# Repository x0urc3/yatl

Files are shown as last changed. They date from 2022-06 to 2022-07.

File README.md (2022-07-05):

# [Work-in-Progress] Yet Another Temperature Logger
A coin cell powered precision temperature logger

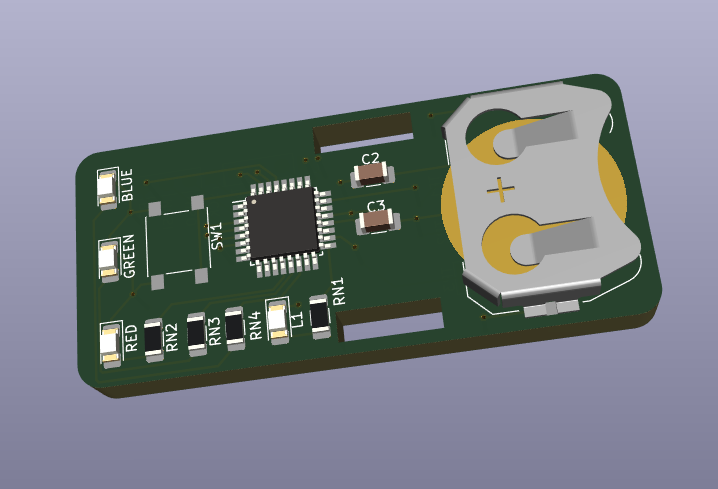
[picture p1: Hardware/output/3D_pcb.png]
PCB 3D view


# Development tools
1. [Kicad](https://www.kicad.org/)
2. [PlatformIO](https://platformio.org/)
3. Python/Bash

# Release
## Version 0.5
- Initial prototype
- ATMega48 microcontroller and LMT86 temperature sensor
- Temperature data is stored in the ATMega48 EEPROM. Sampled every 2 minutes for a duration of 8 hours

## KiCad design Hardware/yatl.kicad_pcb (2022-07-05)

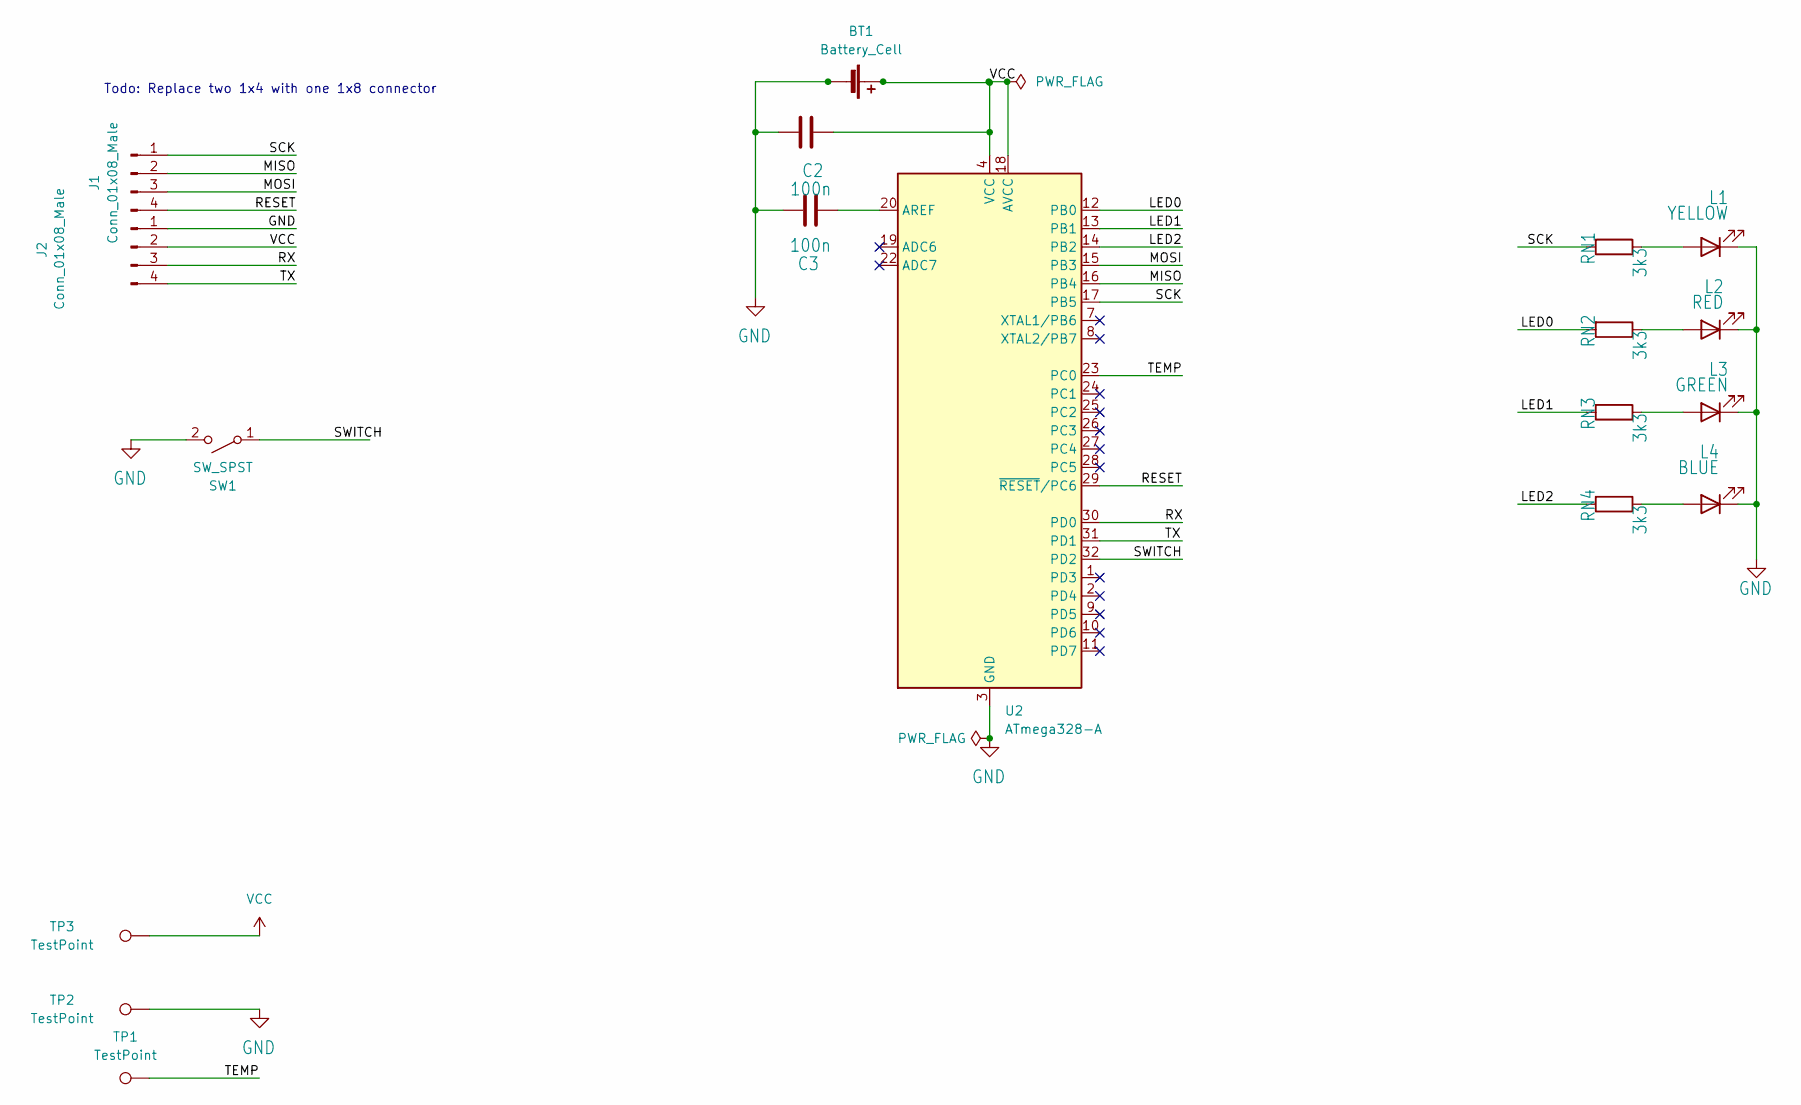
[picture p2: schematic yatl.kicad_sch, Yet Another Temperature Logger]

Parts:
BT1: Battery_Cell; BatteryHolder_Keystone_3034_1x20mm
C2, C3: 100n; C_1206_3216Metric_Pad1.33x1.80mm_HandSolder
J1, J2: Conn_01x08_Male; Testpoint_1x04_P2.54mm
L1: YELLOW; LED_1206_3216Metric_Pad1.42x1.75mm_HandSolder
L2: RED; LED_1206_3216Metric_Pad1.42x1.75mm_HandSolder
L3: GREEN; LED_1206_3216Metric_Pad1.42x1.75mm_HandSolder
L4: BLUE; LED_1206_3216Metric_Pad1.42x1.75mm_HandSolder
RN1, RN2, RN3, RN4: 3k3; R_1206_3216Metric_Pad1.30x1.75mm_HandSolder
SW1: SW_SPST; SW_Push_1P1T_NO_6x6mm_H9.5mm
TP1, TP2, TP3: TestPoint; TestPoint_Pad_3.0x3.0mm
U2: ATmega328-A; TQFP-32_7x7mm_P0.8mm

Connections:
/LED0: RN2.2, U2.12 (PB0)
/LED1: RN3.2, U2.13 (PB1)
/LED2: RN4.2, U2.14 (PB2)
/MISO: J1.2, U2.16 (PB4)
/MOSI: J1.3, U2.15 (PB3)
/RESET: J1.4, U2.29 (~RESET/PC6)
/RX: J2.3, U2.30 (PD0)
/SCK: J1.1, RN1.2, U2.17 (PB5)
/SWITCH: SW1.1 (A), U2.32 (PD2)
/TEMP: TP1.1, U2.23 (PC0)
/TX: J2.4, U2.31 (PD1)
GND: BT1.2 (-), C2.1, C3.2, J2.1, L1.1 (K), L2.1 (K), L3.1 (K), L4.1 (K), SW1.2 (B), TP2.1, U2.3 (GND), U2.5 (GND), U2.21 (GND)
unnamed: C3.1, U2.20 (AREF)
unnamed: L1.2 (A), RN1.1
unnamed: L2.2 (A), RN2.1
unnamed: L3.2 (A), RN3.1
unnamed: L4.2 (A), RN4.1
VCC: BT1.1 (+), C2.2, J2.2, TP3.1, U2.4 (VCC), U2.6 (VCC), U2.18 (AVCC)

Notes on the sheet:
Todo: Replace two 1x4 with one 1x8 connector

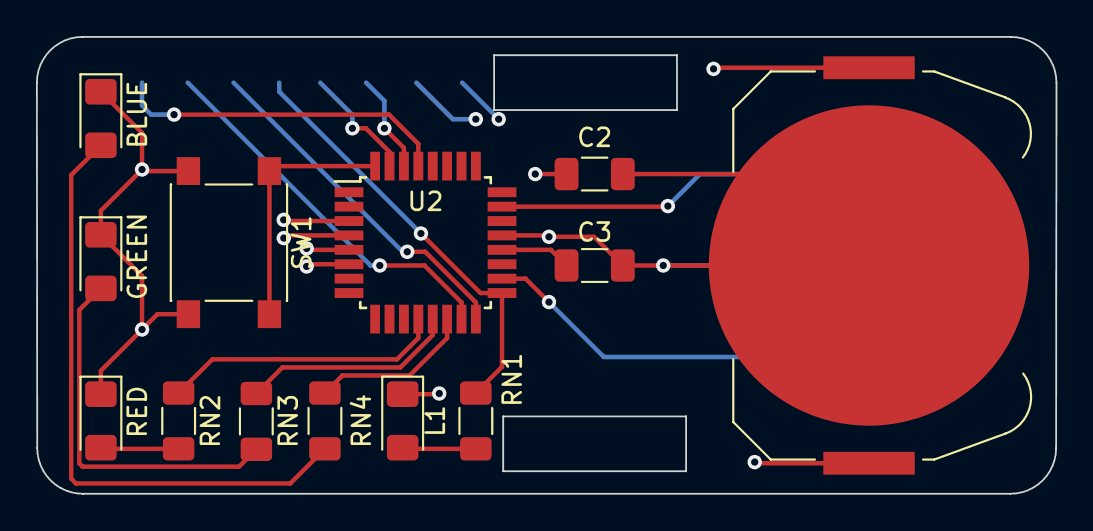
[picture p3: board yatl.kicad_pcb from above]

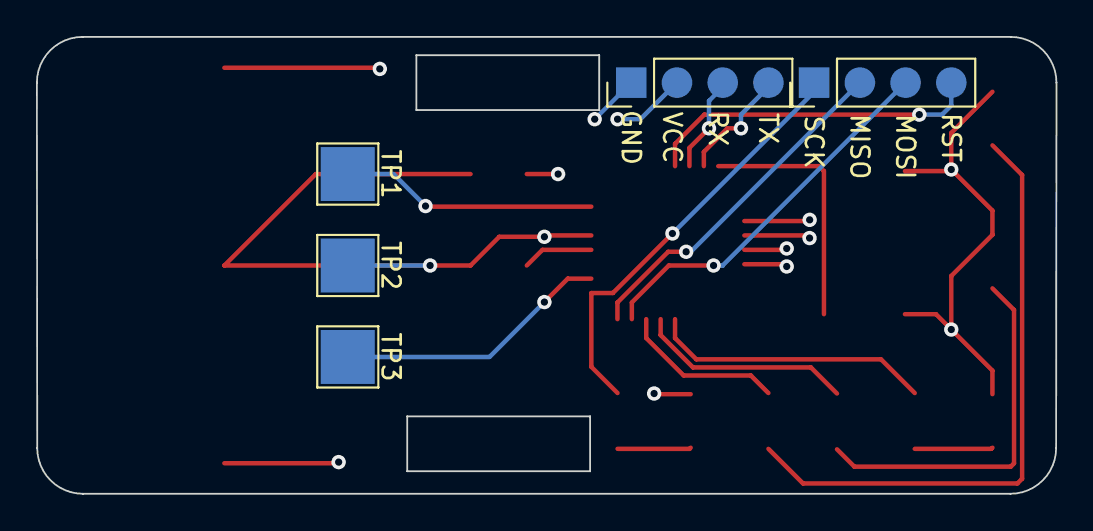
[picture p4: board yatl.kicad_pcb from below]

Board: 4 copper layers, 56.6 x 25.4 mm, 18 parts (5 on the bottom side), 18 nets.

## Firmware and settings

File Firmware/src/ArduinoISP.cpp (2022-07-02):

// ArduinoISP
// Copyright (c) 2008-2011 Randall Bohn
// If you require a license, see
// https://opensource.org/licenses/bsd-license.php
//
// This sketch turns the Arduino into a AVRISP using the following Arduino pins:
//
// Pin 10 is used to reset the target microcontroller.
//
// By default, the hardware SPI pins MISO, MOSI and SCK are used to communicate
// with the target. On all Arduinos, these pins can be found
// on the ICSP/SPI header:
//
//               MISO °. . 5V (!) Avoid this pin on Due, Zero...
//               SCK   . . MOSI
//                     . . GND
//
// On some Arduinos (Uno,...), pins MOSI, MISO and SCK are the same pins as
// digital pin 11, 12 and 13, respectively. That is why many tutorials instruct
// you to hook up the target to these pins. If you find this wiring more
// practical, have a define USE_OLD_STYLE_WIRING. This will work even when not
// using an Uno. (On an Uno this is not needed).
//
// Alternatively you can use any other digital pin by configuring
// software ('BitBanged') SPI and having appropriate defines for PIN_MOSI,
// PIN_MISO and PIN_SCK.
//
// IMPORTANT: When using an Arduino that is not 5V tolerant (Due, Zero, ...) as
// the programmer, make sure to not expose any of the programmer's pins to 5V.
// A simple way to accomplish this is to power the complete system (programmer
// and target) at 3V3.
//
// Put an LED (with resistor) on the following pins:
// 9: Heartbeat   - shows the programmer is running
// 8: Error       - Lights up if something goes wrong (use red if that makes sense)
// 7: Programming - In communication with the target
//

#include "Arduino.h"
#undef SERIAL


#define PROG_FLICKER true

// Configure SPI clock (in Hz).
// E.g. for an ATtiny @ 128 kHz: the datasheet states that both the high and low
// SPI clock pulse must be > 2 CPU cycles, so take 3 cycles i.e. divide target
// f_cpu by 6:
//     #define SPI_CLOCK            (128000/6)
//
// A clock slow enough for an ATtiny85 @ 1 MHz, is a reasonable default:

#define SPI_CLOCK 		(1000000/6)


// Select hardware or software SPI, depending on SPI clock.
// Currently only for AVR, for other architectures (Due, Zero,...), hardware SPI
// is probably too fast anyway.

#if defined(ARDUINO_ARCH_AVR)

  #if SPI_CLOCK > (F_CPU / 128)
    #define USE_HARDWARE_SPI
  #endif

#endif

// Configure which pins to use:

// The standard pin configuration.
#ifndef ARDUINO_HOODLOADER2

  #define RESET     10 // Use pin 10 to reset the target rather than SS
  #define LED_HB    9
  #define LED_ERR   8
  #define LED_PMODE 7

  // Uncomment following line to use the old Uno style wiring
  // (using pin 11, 12 and 13 instead of the SPI header) on Leonardo, Due...

  // #define USE_OLD_STYLE_WIRING

  #ifdef USE_OLD_STYLE_WIRING

    #define PIN_MOSI	11
    #define PIN_MISO	12
    #define PIN_SCK		13

  #endif

  // HOODLOADER2 means running sketches on the ATmega16U2 serial converter chips
  // on Uno or Mega boards. We must use pins that are broken out:
#else

  #define RESET     	4
  #define LED_HB    	7
  #define LED_ERR   	6
  #define LED_PMODE 	5

#endif

// By default, use hardware SPI pins:
#ifndef PIN_MOSI
  #define PIN_MOSI 	MOSI
#endif

#ifndef PIN_MISO
  #define PIN_MISO 	MISO
#endif

#ifndef PIN_SCK
  #define PIN_SCK 	SCK
#endif

// Force bitbanged SPI if not using the hardware SPI pins:
#if (PIN_MISO != MISO) ||  (PIN_MOSI != MOSI) || (PIN_SCK != SCK)
  #undef USE_HARDWARE_SPI
#endif


// Configure the serial port to use.
//
// Prefer the USB virtual serial port (aka. native USB port), if the Arduino has one:
//   - it does not autoreset (except for the magic baud rate of 1200).
//   - it is more reliable because of USB handshaking.
//
// Leonardo and similar have an USB virtual serial port: 'Serial'.
// Due and Zero have an USB virtual serial port: 'SerialUSB'.
//
// On the Due and Zero, 'Serial' can be used too, provided you disable autoreset.
// To use 'Serial': #define SERIAL Serial

#ifdef SERIAL_PORT_USBVIRTUAL
  #define SERIAL SERIAL_PORT_USBVIRTUAL
#else
  #define SERIAL Serial
#endif


// Configure the baud rate:

#define BAUDRATE	19200
// #define BAUDRATE	115200
// #define BAUDRATE	1000000


#define HWVER 2
#define SWMAJ 1
#define SWMIN 18

// STK Definitions
#define STK_OK      0x10
#define STK_FAILED  0x11
#define STK_UNKNOWN 0x12
#define STK_INSYNC  0x14
#define STK_NOSYNC  0x15
#define CRC_EOP     0x20 //ok it is a space...

void pulse(int pin, int times);

#ifdef USE_HARDWARE_SPI
#include "SPI.h"
#else

#define SPI_MODE0 0x00

#if !defined(ARDUINO_API_VERSION) || ARDUINO_API_VERSION != 10001 // A SPISettings class is declared by ArduinoCore-API 1.0.1
class SPISettings {
  public:
    // clock is in Hz
    SPISettings(uint32_t clock, uint8_t bitOrder, uint8_t dataMode) : clockFreq(clock) {
      (void) bitOrder;
      (void) dataMode;
    };

    uint32_t getClockFreq() const {
      return clockFreq;
    }

  private:
    uint32_t clockFreq;
};
#endif  // !defined(ARDUINO_API_VERSION)

class BitBangedSPI {
  public:
    void begin() {
      digitalWrite(PIN_SCK, LOW);
      digitalWrite(PIN_MOSI, LOW);
      pinMode(PIN_SCK, OUTPUT);
      pinMode(PIN_MOSI, OUTPUT);
      pinMode(PIN_MISO, INPUT);
    }

    void beginTransaction(SPISettings settings) {
      pulseWidth = (500000 + settings.getClockFreq() - 1) / settings.getClockFreq();
      if (pulseWidth == 0) {
        pulseWidth = 1;
      }
    }

    void end() {}

    uint8_t transfer(uint8_t b) {
      for (unsigned int i = 0; i < 8; ++i) {
        digitalWrite(PIN_MOSI, (b & 0x80) ? HIGH : LOW);
        digitalWrite(PIN_SCK, HIGH);
        delayMicroseconds(pulseWidth);
        b = (b << 1) | digitalRead(PIN_MISO);
        digitalWrite(PIN_SCK, LOW); // slow pulse
        delayMicroseconds(pulseWidth);
      }
      return b;
    }

  private:
    unsigned long pulseWidth; // in microseconds
};

static BitBangedSPI SPI;

#endif


int ISPError = 0;
int pmode = 0;
// address for reading and writing, set by 'U' command
unsigned int here;
uint8_t buff[256]; // global block storage

#define beget16(addr) (*addr * 256 + *(addr+1) )
typedef struct param {
  uint8_t devicecode;
  uint8_t revision;
  uint8_t progtype;
  uint8_t parmode;
  uint8_t polling;
  uint8_t selftimed;
  uint8_t lockbytes;
  uint8_t fusebytes;
  uint8_t flashpoll;
  uint16_t eeprompoll;
  uint16_t pagesize;
  uint16_t eepromsize;
  uint32_t flashsize;
}
parameter;

parameter param;

// this provides a heartbeat on pin 9, so you can tell the software is running.
uint8_t hbval = 128;
int8_t hbdelta = 8;
void heartbeat() {
  static unsigned long last_time = 0;
  unsigned long now = millis();
  if ((now - last_time) < 40) {
    return;
  }
  last_time = now;
  if (hbval > 192) {
    hbdelta = -hbdelta;
  }
  if (hbval < 32) {
    hbdelta = -hbdelta;
  }
  hbval += hbdelta;
  analogWrite(LED_HB, hbval);
}

static bool rst_active_high;

void reset_target(bool reset) {
  digitalWrite(RESET, ((reset && rst_active_high) || (!reset && !rst_active_high)) ? HIGH : LOW);
}


uint8_t getch() {
  while (!SERIAL.available());
  return SERIAL.read();
}
void fill(int n) {
  for (int x = 0; x < n; x++) {
    buff[x] = getch();
  }
}

#define PTIME 30
void pulse(int pin, int times) {
  do {
    digitalWrite(pin, HIGH);
    delay(PTIME);
    digitalWrite(pin, LOW);
    delay(PTIME);
  } while (times--);
}

void prog_lamp(int state) {
  if (PROG_FLICKER) {
    digitalWrite(LED_PMODE, state);
  }
}

uint8_t spi_transaction(uint8_t a, uint8_t b, uint8_t c, uint8_t d) {
  SPI.transfer(a);
  SPI.transfer(b);
  SPI.transfer(c);
  return SPI.transfer(d);
}

void empty_reply() {
  if (CRC_EOP == getch()) {
    SERIAL.print((char)STK_INSYNC);
    SERIAL.print((char)STK_OK);
  } else {
    ISPError++;
    SERIAL.print((char)STK_NOSYNC);
  }
}

void breply(uint8_t b) {
  if (CRC_EOP == getch()) {
    SERIAL.print((char)STK_INSYNC);
    SERIAL.print((char)b);
    SERIAL.print((char)STK_OK);
  } else {
    ISPError++;
    SERIAL.print((char)STK_NOSYNC);
  }
}

void get_version(uint8_t c) {
  switch (c) {
    case 0x80:
      breply(HWVER);
      break;
    case 0x81:
      breply(SWMAJ);
      break;
    case 0x82:
      breply(SWMIN);
      break;
    case 0x93:
      breply('S'); // serial programmer
      break;
    default:
      breply(0);
  }
}

void set_parameters() {
  // call this after reading parameter packet into buff[]
  param.devicecode = buff[0];
  param.revision   = buff[1];
  param.progtype   = buff[2];
  param.parmode    = buff[3];
  param.polling    = buff[4];
  param.selftimed  = buff[5];
  param.lockbytes  = buff[6];
  param.fusebytes  = buff[7];
  param.flashpoll  = buff[8];
  // ignore buff[9] (= buff[8])
  // following are 16 bits (big endian)
  param.eeprompoll = beget16(&buff[10]);
  param.pagesize   = beget16(&buff[12]);
  param.eepromsize = beget16(&buff[14]);

  // 32 bits flashsize (big endian)
  param.flashsize = buff[16] * 0x01000000
                    + buff[17] * 0x00010000
                    + buff[18] * 0x00000100
                    + buff[19];

  // AVR devices have active low reset, AT89Sx are active high
  rst_active_high = (param.devicecode >= 0xe0);
}

void start_pmode() {

  // Reset target before driving PIN_SCK or PIN_MOSI

  // SPI.begin() will configure SS as output, so SPI master mode is selected.
  // We have defined RESET as pin 10, which for many Arduinos is not the SS pin.
  // So we have to configure RESET as output here,
  // (reset_target() first sets the correct level)
  reset_target(true);
  pinMode(RESET, OUTPUT);
  SPI.begin();
  SPI.beginTransaction(SPISettings(SPI_CLOCK, MSBFIRST, SPI_MODE0));

  // See AVR datasheets, chapter "SERIAL_PRG Programming Algorithm":

  // Pulse RESET after PIN_SCK is low:
  digitalWrite(PIN_SCK, LOW);
  delay(20); // discharge PIN_SCK, value arbitrarily chosen
  reset_target(false);
  // Pulse must be minimum 2 target CPU clock cycles so 100 usec is ok for CPU
  // speeds above 20 KHz
  delayMicroseconds(100);
  reset_target(true);

  // Send the enable programming command:
  delay(50); // datasheet: must be > 20 msec
  spi_transaction(0xAC, 0x53, 0x00, 0x00);
  pmode = 1;
}

void end_pmode() {
  SPI.end();
  // We're about to take the target out of reset so configure SPI pins as input
  pinMode(PIN_MOSI, INPUT);
  pinMode(PIN_SCK, INPUT);
  reset_target(false);
  pinMode(RESET, INPUT);
  pmode = 0;
}

void universal() {
  uint8_t ch;

  fill(4);
  ch = spi_transaction(buff[0], buff[1], buff[2], buff[3]);
  breply(ch);
}

void flash(uint8_t hilo, unsigned int addr, uint8_t data) {
  spi_transaction(0x40 + 8 * hilo,
                  addr >> 8 & 0xFF,
                  addr & 0xFF,
                  data);
}
void commit(unsigned int addr) {
  if (PROG_FLICKER) {
    prog_lamp(LOW);
  }
  spi_transaction(0x4C, (addr >> 8) & 0xFF, addr & 0xFF, 0);
  if (PROG_FLICKER) {
    delay(PTIME);
    prog_lamp(HIGH);
  }
}

unsigned int current_page() {
  if (param.pagesize == 32) {
    return here & 0xFFFFFFF0;
  }
  if (param.pagesize == 64) {
    return here & 0xFFFFFFE0;
  }
  if (param.pagesize == 128) {
    return here & 0xFFFFFFC0;
  }
  if (param.pagesize == 256) {
    return here & 0xFFFFFF80;
  }
  return here;
}

uint8_t write_flash_pages(int length) {
  int x = 0;
  unsigned int page = current_page();
  while (x < length) {
    if (page != current_page()) {
      commit(page);
      page = current_page();
    }
    flash(LOW, here, buff[x++]);
    flash(HIGH, here, buff[x++]);
    here++;
  }

  commit(page);

  return STK_OK;
}

void write_flash(int length) {
  fill(length);
  if (CRC_EOP == getch()) {
    SERIAL.print((char) STK_INSYNC);
    SERIAL.print((char) write_flash_pages(length));
  } else {
    ISPError++;
    SERIAL.print((char) STK_NOSYNC);
  }
}

// write (length) bytes, (start) is a byte address
uint8_t write_eeprom_chunk(unsigned int start, unsigned int length) {
  // this writes byte-by-byte, page writing may be faster (4 bytes at a time)
  fill(length);
  prog_lamp(LOW);
  for (unsigned int x = 0; x < length; x++) {
    unsigned int addr = start + x;
    spi_transaction(0xC0, (addr >> 8) & 0xFF, addr & 0xFF, buff[x]);
    delay(45);
  }
  prog_lamp(HIGH);
  return STK_OK;
}

#define EECHUNK (32)
uint8_t write_eeprom(unsigned int length) {
  // here is a word address, get the byte address
  unsigned int start = here * 2;
  unsigned int remaining = length;
  if (length > param.eepromsize) {
    ISPError++;
    return STK_FAILED;
  }
  while (remaining > EECHUNK) {
    write_eeprom_chunk(start, EECHUNK);
    start += EECHUNK;
    remaining -= EECHUNK;
  }
  write_eeprom_chunk(start, remaining);
  return STK_OK;
}

void program_page() {
  char result = (char) STK_FAILED;
  unsigned int length = 256 * getch();
  length += getch();
  char memtype = getch();
  // flash memory @here, (length) bytes
  if (memtype == 'F') {
    write_flash(length);
    return;
  }
  if (memtype == 'E') {
    result = (char)write_eeprom(length);
    if (CRC_EOP == getch()) {
      SERIAL.print((char) STK_INSYNC);
      SERIAL.print(result);
    } else {
      ISPError++;
      SERIAL.print((char) STK_NOSYNC);
    }
    return;
  }
  SERIAL.print((char)STK_FAILED);
  return;
}

uint8_t flash_read(uint8_t hilo, unsigned int addr) {
  return spi_transaction(0x20 + hilo * 8,
                         (addr >> 8) & 0xFF,
                         addr & 0xFF,
                         0);
}

char flash_read_page(int length) {
  for (int x = 0; x < length; x += 2) {
    uint8_t low = flash_read(LOW, here);
    SERIAL.print((char) low);
    uint8_t high = flash_read(HIGH, here);
    SERIAL.print((char) high);
    here++;
  }
  return STK_OK;
}

char eeprom_read_page(int length) {
  // here again we have a word address
  int start = here * 2;
  for (int x = 0; x < length; x++) {
    int addr = start + x;
    uint8_t ee = spi_transaction(0xA0, (addr >> 8) & 0xFF, addr & 0xFF, 0xFF);
    SERIAL.print((char) ee);
  }
  return STK_OK;
}

void read_page() {
  char result = (char)STK_FAILED;
  int length = 256 * getch();
  length += getch();
  char memtype = getch();
  if (CRC_EOP != getch()) {
    ISPError++;
    SERIAL.print((char) STK_NOSYNC);
    return;
  }
  SERIAL.print((char) STK_INSYNC);
  if (memtype == 'F') {
    result = flash_read_page(length);
  }
  if (memtype == 'E') {
    result = eeprom_read_page(length);
  }
  SERIAL.print(result);
}

void read_signature() {
  if (CRC_EOP != getch()) {
    ISPError++;
    SERIAL.print((char) STK_NOSYNC);
    return;
  }
  SERIAL.print((char) STK_INSYNC);
  uint8_t high = spi_transaction(0x30, 0x00, 0x00, 0x00);
  SERIAL.print((char) high);
  uint8_t middle = spi_transaction(0x30, 0x00, 0x01, 0x00);
  SERIAL.print((char) middle);
  uint8_t low = spi_transaction(0x30, 0x00, 0x02, 0x00);
  SERIAL.print((char) low);
  SERIAL.print((char) STK_OK);
}

void avrisp() {
  uint8_t ch = getch();
  switch (ch) {
    case '0': // signon
      ISPError = 0;
      empty_reply();
      break;
    case '1':
      if (getch() == CRC_EOP) {
        SERIAL.print((char) STK_INSYNC);
        SERIAL.print("AVR ISP");
        SERIAL.print((char) STK_OK);
      } else {
        ISPError++;
        SERIAL.print((char) STK_NOSYNC);
      }
      break;
    case 'A':
      get_version(getch());
      break;
    case 'B':
      fill(20);
      set_parameters();
      empty_reply();
      break;
    case 'E': // extended parameters - ignore for now
      fill(5);
      empty_reply();
      break;
    case 'P':
      if (!pmode) {
        start_pmode();
      }
      empty_reply();
      break;
    case 'U': // set address (word)
      here = getch();
      here += 256 * getch();
      empty_reply();
      break;

    case 0x60: //STK_PROG_FLASH
      getch(); // low addr
      getch(); // high addr
      empty_reply();
      break;
    case 0x61: //STK_PROG_DATA
      getch(); // data
      empty_reply();
      break;

    case 0x64: //STK_PROG_PAGE
      program_page();
      break;

    case 0x74: //STK_READ_PAGE 't'
      read_page();
      break;

    case 'V': //0x56
      universal();
      break;
    case 'Q': //0x51
      ISPError = 0;
      end_pmode();
      empty_reply();
      break;

    case 0x75: //STK_READ_SIGN 'u'
      read_signature();
      break;

    // expecting a command, not CRC_EOP
    // this is how we can get back in sync
    case CRC_EOP:
      ISPError++;
      SERIAL.print((char) STK_NOSYNC);
      break;

    // anything else we will return STK_UNKNOWN
    default:
      ISPError++;
      if (CRC_EOP == getch()) {
        SERIAL.print((char)STK_UNKNOWN);
      } else {
        SERIAL.print((char)STK_NOSYNC);
      }
  }
}
//////////////////////////////////////////
//////////////////////////////////////////


////////////////////////////////////
////////////////////////////////////
void setup() {
  SERIAL.begin(BAUDRATE);

  pinMode(LED_PMODE, OUTPUT);
  pulse(LED_PMODE, 2);
  pinMode(LED_ERR, OUTPUT);
  pulse(LED_ERR, 2);
  pinMode(LED_HB, OUTPUT);
  pulse(LED_HB, 2);

}

void loop(void) {
  // is pmode active?
  if (pmode) {
    digitalWrite(LED_PMODE, HIGH);
  } else {
    digitalWrite(LED_PMODE, LOW);
  }
  // is there an error?
  if (ISPError) {
    digitalWrite(LED_ERR, HIGH);
  } else {
    digitalWrite(LED_ERR, LOW);
  }

  // light the heartbeat LED
  heartbeat();
  if (SERIAL.available()) {
    avrisp();
  }
}

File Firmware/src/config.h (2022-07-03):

/* config.h Copyright (c) 2022 Khairulmizam Samsudin <xource@gmail.com
 *
 * Pins and configuration declaration
 *
 */

#ifndef CONFIG_H_
#define CONFIG_H_

#include <avr/io.h>

// Reserved pins    ATMega | Phy |  Uno
// Reset             PC6   |  1  |   reset
// SCK               PB5   |  19 |   13
// MISO              PB4   |  18 |   12
// MOSI              PB3   |  17 |   11
// SDA               PC4   |  27 |   A4
// SCL               PC5   |  28 |   A5
// TX                PD1   |  2  |   1
// RX                PD0   |  3  |   0
// ARef (100nF Gnd)  ARef  |  20 |   ARef

// pinout         ATMega    | Phy  |  Uno
#define LED1        PB0   //       |  x     |  x
#define LED2        PB1   //       |  x     |  x
#define LED3        PB2   //       |  x     |  x
#define LEDDDR      DDRB
#define LEDPORT     PORTB
#define TEMPPIN     0xf0  //   23  |  A0
#define SWITCH      PD2   //       |  x     |  x
#define SWITCH_PIN  PIND
#define SWITCH_PORT PORTD
#define SWITCH_DEBOUNCE_TIME 100

#endif  // CONFIG_H_

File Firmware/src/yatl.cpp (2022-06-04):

/* yatl.cpp Copyright (c) 2022 Khairulmizam Samsudin <xource@gmail.com
 *
 * Firmware for Yet Another Temperature Logger
 * 
 */

#include "adc.h"
#include "trace.h"
#include "usart.h"
#include <avr/io.h>
#include <avr/eeprom.h>
#include <util/delay.h>
#include <avr/sleep.h>

// Reserved pins    ATMega | Phy |  Uno
// Reset             PC6   |  1  |   reset
// SCK               PB5   |  19 |   13
// MISO              PB4   |  18 |   12
// MOSI              PB3   |  17 |   11
// SDA               PC4   |  27 |   A4
// SCL               PC5   |  28 |   A5
// TX                PD1   |  2  |   1
// RX                PD0   |  3  |   0
// ARef (100nF Gnd)  ARef  |  20 |   ARef

// pinout         ATMega    | Phy  |  Uno
#define LED1        PB0   //       |  x     |  x
#define LED2        PB1   //       |  x     |  x
#define LED3        PB2   //       |  x     |  x
#define LEDPIN      PINB
#define LEDPORT     PORTB
#define TEMPPIN     0xf0  //   23  |  A0
#define SWITCH      PD2   //       |  x     |  x
#define SWITCH_PIN  PIND
#define SWITCH_PORT PORTD
#define SWITCH_DEBOUNCE_TIME 100

#define ADC_VREF    50    // Vcc = 5.06
#define TEMP_GAIN   1085  // LMT86: 10.85mV per Celcius 
#define TEMP_OFFSET	21    // Offset for 0deg Celcius

#define ROM_DIRTY 0x7a
#define ROM_SIZE 500
uint8_t EEMEM rom_dirty;
uint16_t EEMEM rom_cnt;
uint8_t EEMEM rom_data[ROM_SIZE];

#define TIMEOUT_MS 2000
#define resetCounterT1() (TCNT1 = 0)
#define expiredCounterT1() ((TCNT1 > TIMEOUT_MS) ? 1 : 0)

void initCounterT1(void) {
    TCCR1B = _BV(CS12) | _BV(CS10); //1Mhz/1024 = 976Hz ~ 1000Hz
}

void initPin(void) {
    SWITCH_PORT |= _BV(SWITCH);      //Enable pullup
}

void initEEPROM(void) {
    uint8_t tt;
    tt = eeprom_read_byte(&rom_dirty);
    if (tt != ROM_DIRTY) {
        TRACE("Reset counter. DIRTY:%d\n",tt);
        tt = eeprom_read_word(&rom_cnt);
        if (tt != 0) {
            TRACE("Reset counter. CNT:%d\n",tt);
            eeprom_update_word(&rom_cnt,0);
        }
    }
}

uint8_t debounce(void) {
    //    TRACE("switch:%d\n", SWITCH_PIN & _BV(SWITCH));
    if (bit_is_clear(SWITCH_PIN, SWITCH)) {      // switch pressed
        _delay_us(SWITCH_DEBOUNCE_TIME);
        if (bit_is_clear(SWITCH_PIN, SWITCH)) {  // still pressed
            return (1);
        }
    }
    return 0;
}

uint16_t getTemp10(void) {
    uint16_t temp;
    uint16_t adc_vref;
    uint16_t adc;

    ADMUX = _BV(REFS0);   // Vcc as Voltage Ref 
    ADMUX &= TEMPPIN;     // Select temperature pin
    _delay_ms(10);         // Settling time after changing ADMUX
    ADCSRA |= _BV(ADSC);  // Start conversion
    loop_until_bit_is_clear(ADCSRA, ADSC);
    adc = ADC;
    TRACE("ADC: %d\n", adc);
    //T = ((ADC/1024)*VRef - TEMP_OFFSET ) / -TEMP_GAIN
    //temp =  (TEMP_OFFSET*1024 - adc*ADC_VREF)/ (TEMP_GAIN*0.01024);
    adc_vref =  getVcc100()/10;
    temp =  (TEMP_OFFSET*1024 - adc*adc_vref) / (TEMP_GAIN*0.01024);
    return (temp); 
}

void doSleep() {
 //cbi(ADCSRA,ADEN); // Switch Analog to Digital converter OFF

 set_sleep_mode(SLEEP_MODE_PWR_DOWN); // Set sleep mode
 sleep_mode(); // System sleeps here
 //sbi(ADCSRA,ADEN);  // Switch Analog to Digital converter ON
}

void setup(void) {
    initADC();
    initEEPROM();
    initPin();
    initCounterT1();
    TRACE_init();
/*
    pinMode(LEDPIN1, OUTPUT);
    pinMode(LEDPIN2, OUTPUT);
    pinMode(LEDPIN3, OUTPUT);
    pinMode(GATEPIN, OUTPUT);
    pinMode(TEMPPIN, INPUT);
    pinMode(SWITCHPIN, INPUT_PULLUP);
*/
    //Serial.begin(9600);
    //	mySerial.begin(9600);
    //    OSCCAL=200;

    //initUSART();
}



int main(void) {
    setup();
    for (;;) {
        uint8_t stateClicked = 0;
        uint8_t clickCount = 0;

        //TRACE("Internal temp: %d", getInternalTemp());
        //TRACE("test %d\n", 5);
        if (debounce()) {
            if (stateClicked == 0) {
                clickCount += 1;
                stateClicked = 1;
                TRACE("click:%d\n", clickCount);
            }
        } else {
            stateClicked = 0;
        }

        if (expiredCounterT1()) {
            TRACE("Change state. click:%d\n", clickCount);
            resetCounterT1();
            clickCount = 0;
        }
        //_delay_ms(1000);

    }
    return(0);
}

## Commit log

2022-05-25 Add function to read internal temperature sensor
2022-05-25 Add LMT86 temperature sensor function
2022-05-26 Add ADC prescaler for different board
2022-05-26 BUG: Identified bug in getInternalTemp()
    [yatl.cpp]
2022-05-26 Add getVCC100() to determine battery voltage
2022-05-26 Fix bug in getInternalTemp() when changing input channel - Add settling time after changing ADMUX - Add/increase settling time for other ADC related functions
    [yatl.cpp]
2022-05-26 Refactor code to print one floating point
2022-05-26 build: Add target environment without Arduino framework
2022-05-28 Initialize Kicad project and copied Arduino Uno microcontroller schematic
    [yatl.kicad_pcb, yatl.kicad_sch]
2022-05-31 Added schematic and update pins definition
    [yatl.kicad_sch]
2022-05-31 Route PCB and update schematics - Add 1x4 testpoint footprint in a project library - Replace LMT86 footprint with 3 1x1 test point - Fix battery decoupling capacitor wiring
    [yatl.kicad_pcb, yatl.kicad_sch]
2022-06-02 Add USART - Add rx/tx USART functionality - Rename debug.h to trace.h - Add USART feature to TRACE - Automatic detection of Arduino Serial library
2022-06-02 Move generic adc function to separate file
2022-06-02 Use getVcc100() to define adc vref
2022-06-03 Add configuration and fuses for target ATmega328p
2022-06-04 Add switch definition and function
2022-06-04 Remove Arduino framework dependencies
2022-06-04 Remove Arduino framework dependencies and use function-like macro
2022-06-05 Enhance tracer.h - Add different verbosity level to TRACER macro - TRACERVERBOSE default to 1 - renamed enabler flag to TRACER
2022-06-05 Change logic soo that smaller verbosity level will be printed
2022-06-06 Power down mode disable ALL clock and oscillator
2022-06-06 Add and track different UI state
2022-06-06 Move tracer initialization before setup()
2022-06-06 Add state variable for use in each loop and use currentState across loop
2022-06-07 Add cpplint configuration file
    [CPPLINT.cfg]
2022-06-07 Change the root dir for cpplint
    [CPPLINT.cfg]
2022-06-09 Separate env for develop and debug - develop enable TRACE - debug enable symbolic debug info for gdb
2022-07-01 Fix pitch between connectors
    [yatl.kicad_pcb, yatl.kicad_sch]
2022-07-02 Move getTem10() to adc.h
2022-07-02 Add new source file to test board functionality
2022-07-02 Test all LED
2022-07-02 Add interrupt switch to flip direction of LED shifting
    [board-test.c]
2022-07-02 Add temperature sensing
2022-07-03 Change LED resistor to 2k
    [yatl.kicad_sch]
2022-07-03 Rename LED and reposition connector label
    [yatl.kicad_pcb]
2022-07-03 ATMega48 is for environment release & board. ATMega328 for dev and debug
2022-07-03 Add doBlinkLED() after timer expired to confirm state selection
2022-07-03 Add showResultLED() to indicate battery and storage value using LED
2022-07-03 Update fuse flag for ATmega48
2022-07-03 Multiple enhancement - Add argument to upload ArduinoISP - Add variable to define AVR part id for avrdude - Dump eeprom to stdout
2022-07-03 Update fuse for ATMega328P and ATMega48
2022-07-04 Add test for switching on led
2022-07-04 Enable arduino framework to use native Arduino test
2022-07-05 Increase LED resistor value to reduce current consumption
    [yatl.kicad_pcb, yatl.kicad_sch]
2022-07-05 Remove LMT86 decoupling capacitor that cause sudden temperature spike after certain minutes
    [yatl.kicad_pcb, yatl.kicad_sch]
2022-07-05 Add LED indicator when logging started
